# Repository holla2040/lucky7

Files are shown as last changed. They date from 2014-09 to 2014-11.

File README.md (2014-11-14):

Lucky7
======

7-Output Power Control Arduino Shield with sensor inputs and IR sensor<br><br>
Features<br>
1. 7 high-current (12A max) P-channel high-side MOSFETs with gate drivers. These switches have 30mOhm Rds when on. Each output has an LED indicator. 6 of the outputs are PWM controllable.<br>
2. The shield can operate up to 30VDC and supplies this voltage to the Arduino board.<br>
3. Two additional LEDs are connected to Arduino pin 8 and 13.<br>
4. 3 analog inputs: 2 for photocells, 1 for user button.<br>
5. 1 IR sensor input, such as TSOP38238.<br>
6. Input voltage sense to Arduino analog input A0.<br>
7. ATO fuse holder for wire protection in case of shorts to ground.<br>
8. Hardware design and firmware are released CC-BY-SA<br>
<br>
Fully populated and tested board is available for $20 + shipping.  Contact holla@montrosemakerspace.com for more information.
<br>
<br>
Only 10 available, order now!

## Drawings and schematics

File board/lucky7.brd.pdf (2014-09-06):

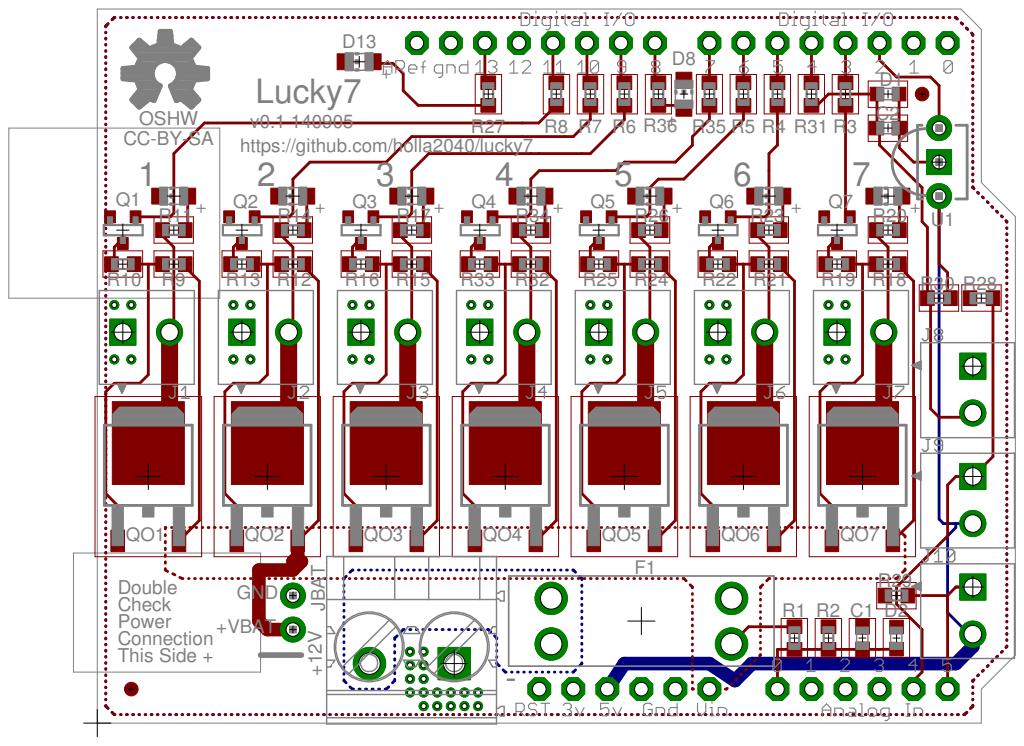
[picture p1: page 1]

- Double Check Power Connection This Side +

+VBAT

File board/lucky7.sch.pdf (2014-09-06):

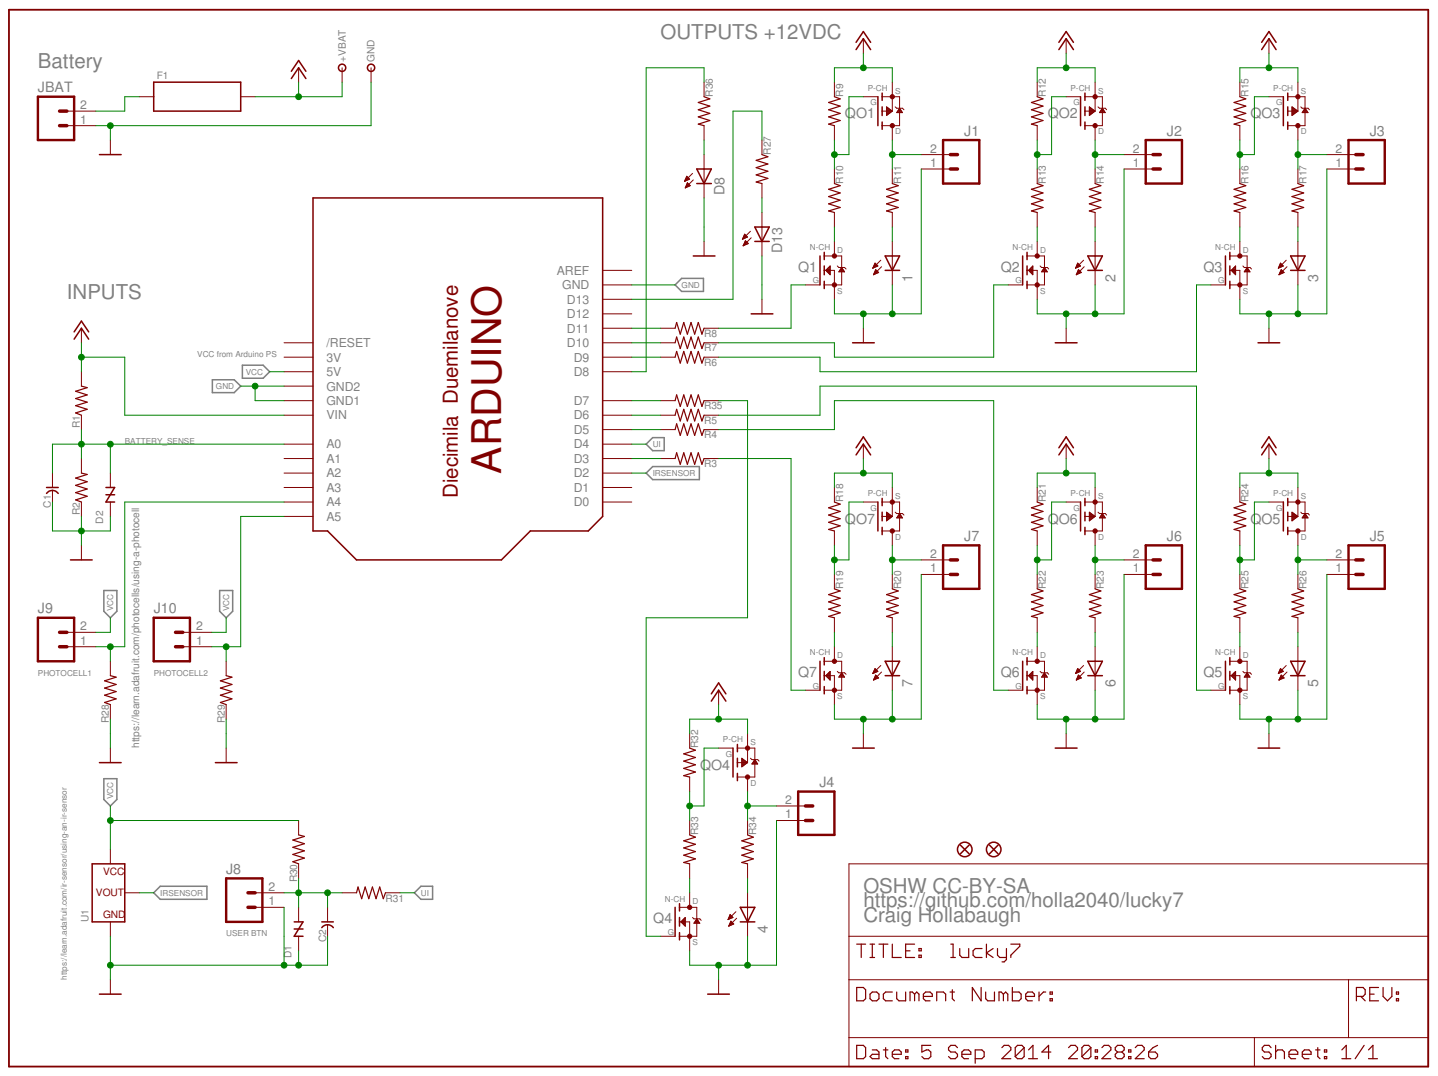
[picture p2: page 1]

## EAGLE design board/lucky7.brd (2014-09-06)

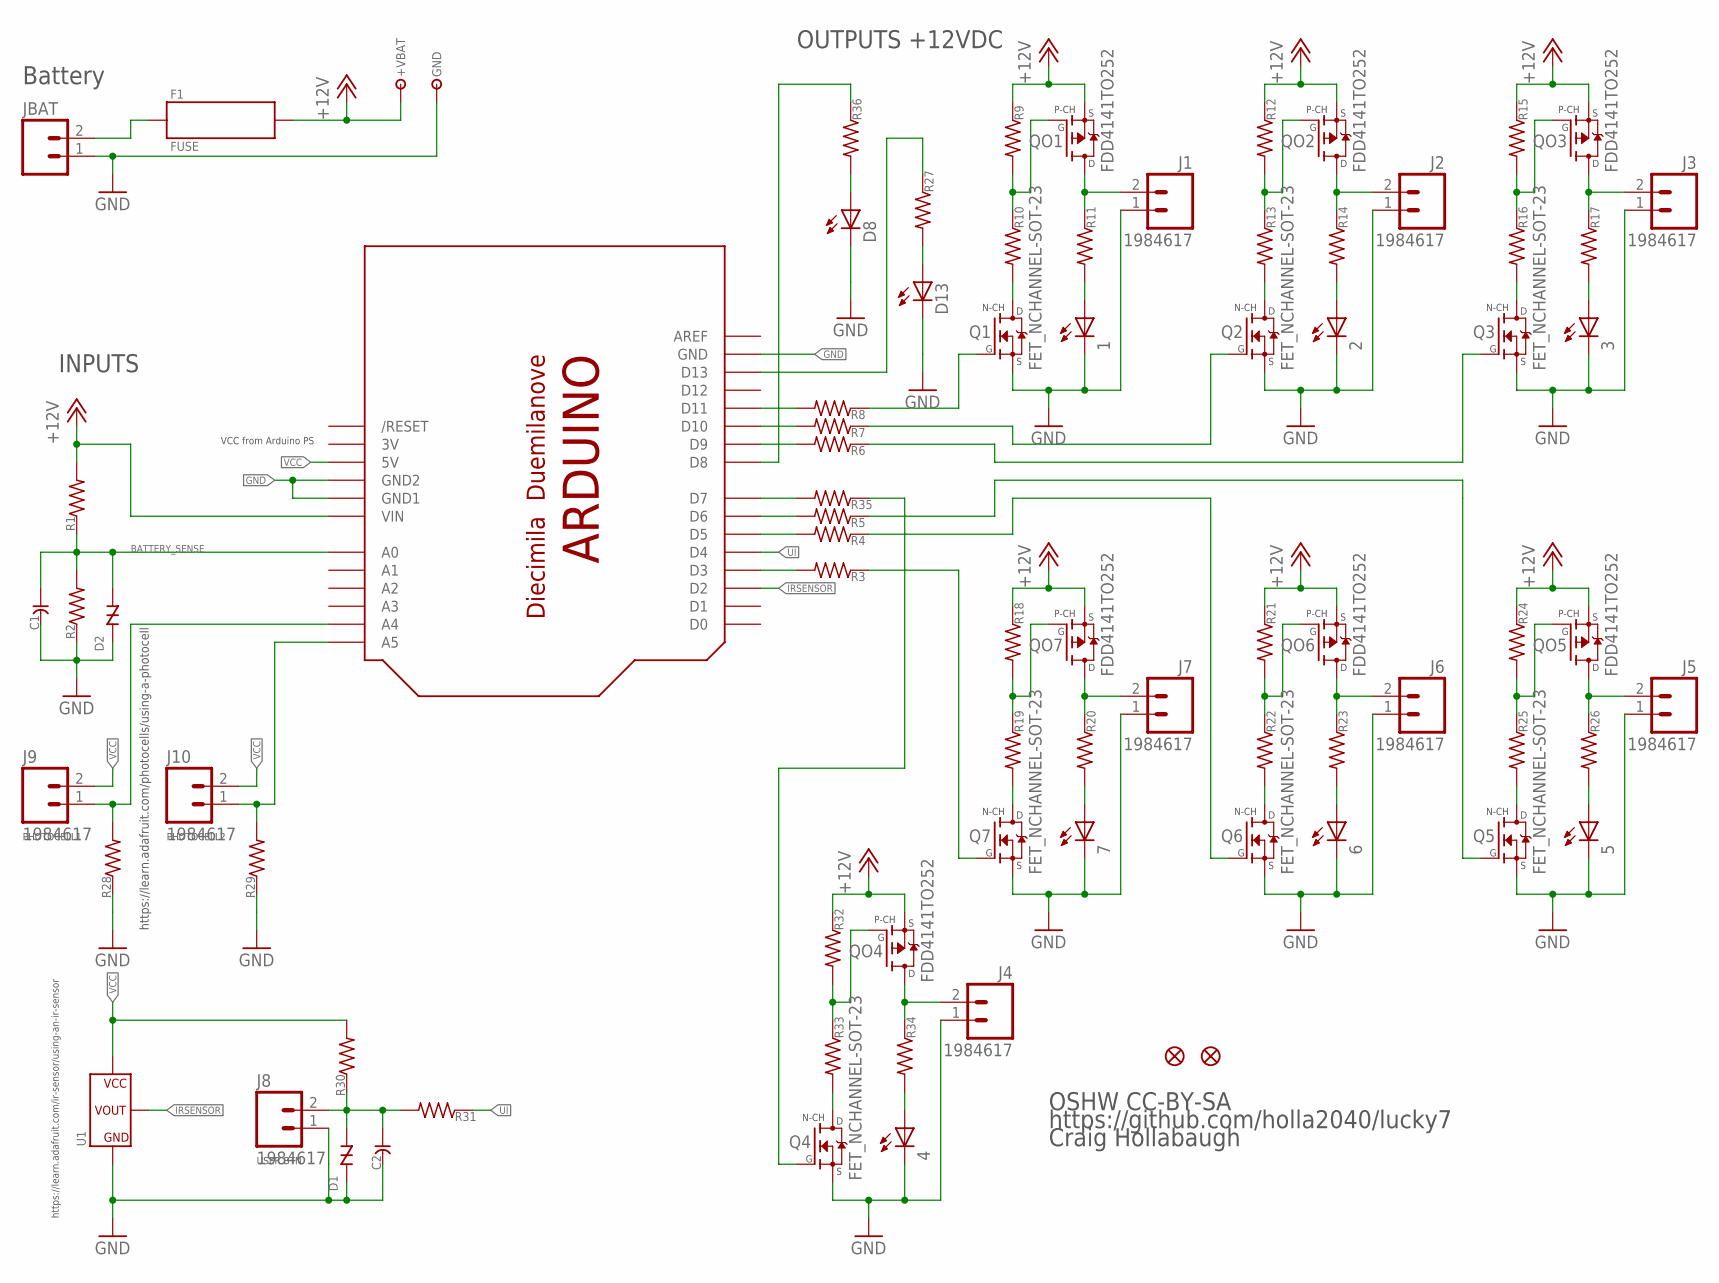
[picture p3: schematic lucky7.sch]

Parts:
1, 2, 3, 4, 5, 6, 7: LEDCHIP-LED0805; CHIP-LED0805
+VBAT: TESTPOINTTHRU; TPTHRU
C1, C2: C-USC0603; C0603
D1, D2: TVS0603; TVS-0603
D8, D13: LEDCHIP-LED0805; CHIP-LED0805
F1: FUSE; FUSE-3557-2
GND: TESTPOINTTHRU; TPTHRU
J1, J2, J3, J4, J5, J6, J7, J8, J9, J10: 1984617
JBAT: M02-6.35MM; OSTT702
JP1, JP2: FIDUCIAL1X2; FIDUCIAL-1X2
Q1, Q2, Q3, Q4, Q5, Q6, Q7: FET_NCHANNEL-SOT-23; SOT-23
QO1, QO2, QO3, QO4, QO5, QO6, QO7: FDD4141TO252; TO252
R1, R2, R3, R4, R5, R6, R7, R8, R9, R10, R11, R12, R13, R14, R15, R16, R17, R18, R19, R20, R21, R22, R23, R24, R25, R26, R27, R28, R29, R30, R31, R32, R33, R34, R35, R36: R-US_R0603; R0603
U1: IRDETECTOR-THRU
U100: ARDUINO-BPLACE

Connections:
3V: U100.3V
+12V: +VBAT.1, F1.2@1, F1.2@2, QO1.2 (S), QO2.2 (S), QO3.2 (S), QO4.2 (S), QO5.2 (S), QO6.2 (S), QO7.2 (S), R1.2, R9.1, R12.1, R15.1, R18.1, R21.1, R24.1, R32.1, U100.VIN
BATTERY_SENSE: C1.1, D2.1, R1.1, R2.2, U100.A0
GND: 1.C, 2.C, 3.C, 4.C, 5.C, 6.C, 7.C, C1.2, C2.2, D1.2, D2.2, D8.C, D13.C, GND.1, J1.1, J2.1, J3.1, J4.1, J5.1, J6.1, J7.1, J8.1, JBAT.1, Q1.3 (S), Q2.3 (S), Q3.3 (S), Q4.3 (S), Q5.3 (S), Q6.3 (S), Q7.3 (S), R2.1, R28.1, R29.1, U1.GND, U100.GND, U100.GND1, U100.GND2
IRSENSOR: U1.VOUT, U100.D2
unnamed: QO1.1 (G), R9.2, R10.1
unnamed: Q1.1 (D), R10.2
unnamed: R8.2, U100.D11
unnamed: J9.1, R28.2, U100.A4
unnamed: 1.A, R11.2
unnamed: R7.2, U100.D10
unnamed: R6.2, U100.D9
unnamed: R5.2, U100.D6
unnamed: R4.2, U100.D5
unnamed: R3.2, U100.D3
unnamed: QO2.1 (G), R12.2, R13.1
unnamed: Q2.1 (D), R13.2
unnamed: 2.A, R14.2
unnamed: QO3.1 (G), R15.2, R16.1
unnamed: Q3.1 (D), R16.2
unnamed: 3.A, R17.2
unnamed: QO7.1 (G), R18.2, R19.1
unnamed: Q7.1 (D), R19.2
unnamed: 7.A, R20.2
unnamed: QO6.1 (G), R21.2, R22.1
unnamed: Q6.1 (D), R22.2
unnamed: 6.A, R23.2
unnamed: QO5.1 (G), R24.2, R25.1
unnamed: Q5.1 (D), R25.2
unnamed: 5.A, R26.2
unnamed: Q1.2 (G), R8.1
unnamed: Q2.2 (G), R7.1
unnamed: Q3.2 (G), R6.1
unnamed: Q5.2 (G), R5.1
unnamed: Q6.2 (G), R4.1
unnamed: Q7.2 (G), R3.1
unnamed: J10.1, R29.2, U100.A5
unnamed: C2.1, D1.1, J8.2, R30.1, R31.2
unnamed: D13.A, R27.2
unnamed: R27.1, U100.D13
unnamed: QO4.1 (G), R32.2, R33.1
unnamed: Q4.1 (D), R33.2
unnamed: D8.A, R36.2
unnamed: R36.1, U100.D8
unnamed: 4.A, R34.2
unnamed: Q4.2 (G), R35.1
unnamed: R35.2, U100.D7
O1: J1.2, QO1.3 (D), R11.1
O2: J2.2, QO2.3 (D), R14.1
O3: J3.2, QO3.3 (D), R17.1
O4: J4.2, QO4.3 (D), R34.1
O5: J5.2, QO5.3 (D), R26.1
O6: J6.2, QO6.3 (D), R23.1
O7: J7.2, QO7.3 (D), R20.1
UI: R31.1, U100.D4
VBAT: F1.1@1, F1.1@2, JBAT.2
VCC: J9.2, J10.2, R30.2, U1.VCC, U100.5V

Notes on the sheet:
PHOTOCELL1
PHOTOCELL2
https://learn.adafruit.com/photocells/using-a-photocell
USER BTN
VCC from Arduino PS
https://learn.adafruit.com/ir-sensor/using-an-ir-sensor
INPUTS
OUTPUTS +12VDC
Battery
https://github.com/holla2040/lucky7
OSHW CC-BY-SA
Craig Hollabaugh

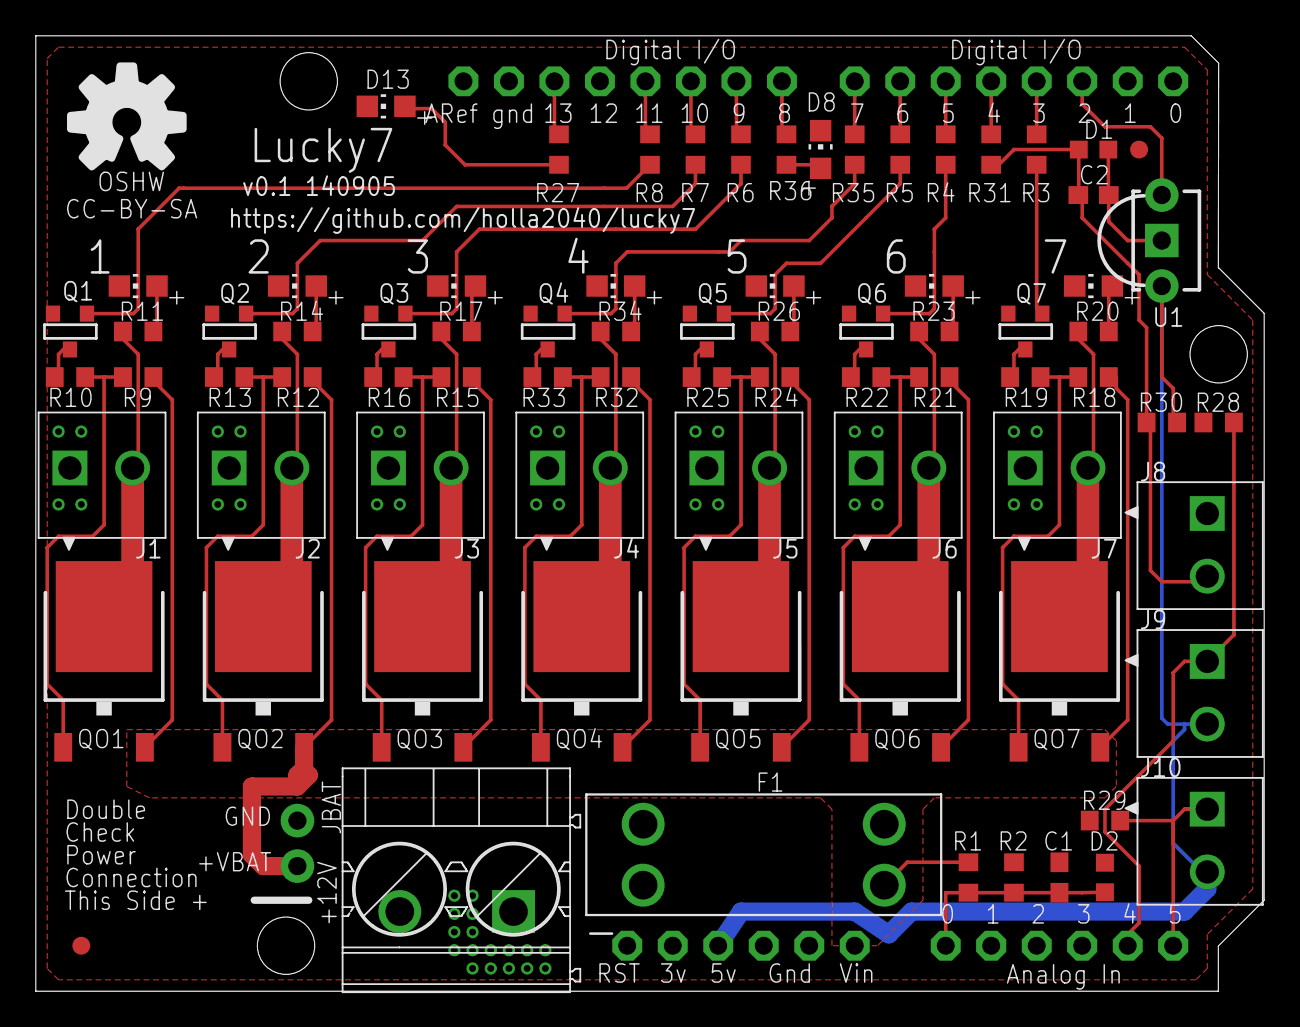
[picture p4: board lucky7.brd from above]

Board: 2 copper layers, 68.6 x 53.3 mm, 81 parts (0 on the bottom side), 56 nets.

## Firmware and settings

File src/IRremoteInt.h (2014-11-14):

/*
 * IRremote
 * Version 0.1 July, 2009
 * Copyright 2009 Ken Shirriff
 * For details, see http://arcfn.com/2009/08/multi-protocol-infrared-remote-library.html
 *
 * Modified by Paul Stoffregen <paul@pjrc.com> to support other boards and timers
 *
 * Interrupt code based on NECIRrcv by Joe Knapp
 * http://www.arduino.cc/cgi-bin/yabb2/YaBB.pl?num=1210243556
 * Also influenced by http://zovirl.com/2008/11/12/building-a-universal-remote-with-an-arduino/
 *
 * JVC and Panasonic protocol added by Kristian Lauszus (Thanks to zenwheel and other people at the original blog post)
 */

#ifndef IRremoteint_h
#define IRremoteint_h

#if defined(ARDUINO) && ARDUINO >= 100
#include <Arduino.h>
#else
#include <WProgram.h>
#endif

// define which timer to use
//
// Uncomment the timer you wish to use on your board.  If you
// are using another library which uses timer2, you have options
// to switch IRremote to use a different timer.

// Arduino Mega
#if defined(__AVR_ATmega1280__) || defined(__AVR_ATmega2560__)
  //#define IR_USE_TIMER1   // tx = pin 11
  #define IR_USE_TIMER2     // tx = pin 9
  //#define IR_USE_TIMER3   // tx = pin 5
  //#define IR_USE_TIMER4   // tx = pin 6
  //#define IR_USE_TIMER5   // tx = pin 46

// Teensy 1.0
#elif defined(__AVR_AT90USB162__)
  #define IR_USE_TIMER1     // tx = pin 17

// Teensy 2.0
#elif defined(__AVR_ATmega32U4__)
  //#define IR_USE_TIMER1   // tx = pin 14
  //#define IR_USE_TIMER3   // tx = pin 9
  #define IR_USE_TIMER4_HS  // tx = pin 10

// Teensy++ 1.0 & 2.0
#elif defined(__AVR_AT90USB646__) || defined(__AVR_AT90USB1286__)
  //#define IR_USE_TIMER1   // tx = pin 25
  #define IR_USE_TIMER2     // tx = pin 1
  //#define IR_USE_TIMER3   // tx = pin 16

// Sanguino
#elif defined(__AVR_ATmega644P__) || defined(__AVR_ATmega644__)
  //#define IR_USE_TIMER1   // tx = pin 13
  #define IR_USE_TIMER2     // tx = pin 14

// Atmega8
#elif defined(__AVR_ATmega8P__) || defined(__AVR_ATmega8__)
  #define IR_USE_TIMER1   // tx = pin 9

// Arduino Duemilanove, Diecimila, LilyPad, Mini, Fio, etc
#else
  #define IR_USE_TIMER1   // tx = pin 9
  //#define IR_USE_TIMER2     // tx = pin 3
#endif



#ifdef F_CPU
#define SYSCLOCK F_CPU     // main Arduino clock
#else
#define SYSCLOCK 16000000  // main Arduino clock
#endif

#define ERR 0
#define DECODED 1


// defines for setting and clearing register bits
#ifndef cbi
#define cbi(sfr, bit) (_SFR_BYTE(sfr) &= ~_BV(bit))
#endif
#ifndef sbi
#define sbi(sfr, bit) (_SFR_BYTE(sfr) |= _BV(bit))
#endif

// Pulse parms are *50-100 for the Mark and *50+100 for the space
// First MARK is the one after the long gap
// pulse parameters in usec
#define NEC_HDR_MARK	9000
#define NEC_HDR_SPACE	4500
#define NEC_BIT_MARK	560
#define NEC_ONE_SPACE	1600
#define NEC_ZERO_SPACE	560
#define NEC_RPT_SPACE	2250

#define SONY_HDR_MARK	2400
#define SONY_HDR_SPACE	600
#define SONY_ONE_MARK	1200
#define SONY_ZERO_MARK	600
#define SONY_RPT_LENGTH 45000
#define SONY_DOUBLE_SPACE_USECS  500  // usually ssee 713 - not using ticks as get number wrapround

// SA 8650B
#define SANYO_HDR_MARK	3500  // seen range 3500
#define SANYO_HDR_SPACE	950 //  seen 950
#define SANYO_ONE_MARK	2400 // seen 2400  
#define SANYO_ZERO_MARK 700 //  seen 700
#define SANYO_DOUBLE_SPACE_USECS  800  // usually ssee 713 - not using ticks as get number wrapround
#define SANYO_RPT_LENGTH 45000

// Mitsubishi RM 75501
// 14200 7 41 7 42 7 42 7 17 7 17 7 18 7 41 7 18 7 17 7 17 7 18 7 41 8 17 7 17 7 18 7 17 7 

// #define MITSUBISHI_HDR_MARK	250  // seen range 3500
#define MITSUBISHI_HDR_SPACE	350 //  7*50+100
#define MITSUBISHI_ONE_MARK	1950 // 41*50-100
#define MITSUBISHI_ZERO_MARK  750 // 17*50-100
// #define MITSUBISHI_DOUBLE_SPACE_USECS  800  // usually ssee 713 - not using ticks as get number wrapround
// #define MITSUBISHI_RPT_LENGTH 45000


#define RC5_T1		889
#define RC5_RPT_LENGTH	46000

#define RC6_HDR_MARK	2666
#define RC6_HDR_SPACE	889
#define RC6_T1		444
#define RC6_RPT_LENGTH	46000

#define SHARP_BIT_MARK 245
#define SHARP_ONE_SPACE 1805
#define SHARP_ZERO_SPACE 795
#define SHARP_GAP 600000
#define SHARP_TOGGLE_MASK 0x3FF
#define SHARP_RPT_SPACE 3000

#define DISH_HDR_MARK 400
#define DISH_HDR_SPACE 6100
#define DISH_BIT_MARK 400
#define DISH_ONE_SPACE 1700
#define DISH_ZERO_SPACE 2800
#define DISH_RPT_SPACE 6200
#define DISH_TOP_BIT 0x8000

#define PANASONIC_HDR_MARK 3502
#define PANASONIC_HDR_SPACE 1750
#define PANASONIC_BIT_MARK 502
#define PANASONIC_ONE_SPACE 1244
#define PANASONIC_ZERO_SPACE 400

#define JVC_HDR_MARK 8000
#define JVC_HDR_SPACE 4000
#define JVC_BIT_MARK 600
#define JVC_ONE_SPACE 1600
#define JVC_ZERO_SPACE 550
#define JVC_RPT_LENGTH 60000

#define LG_HDR_MARK 8000
#define LG_HDR_SPACE 4000
#define LG_BIT_MARK 600
#define LG_ONE_SPACE 1600
#define LG_ZERO_SPACE 550
#define LG_RPT_LENGTH 60000

#define SAMSUNG_HDR_MARK  5000
#define SAMSUNG_HDR_SPACE 5000
#define SAMSUNG_BIT_MARK  560
#define SAMSUNG_ONE_SPACE 1600
#define SAMSUNG_ZERO_SPACE  560
#define SAMSUNG_RPT_SPACE 2250


#define SHARP_BITS 15
#define DISH_BITS 16

#define TOLERANCE 25  // percent tolerance in measurements
#define LTOL (1.0 - TOLERANCE/100.) 
#define UTOL (1.0 + TOLERANCE/100.) 

#define _GAP 5000 // Minimum map between transmissions
#define GAP_TICKS (_GAP/USECPERTICK)

#define TICKS_LOW(us) (int) (((us)*LTOL/USECPERTICK))
#define TICKS_HIGH(us) (int) (((us)*UTOL/USECPERTICK + 1))

// receiver states
#define STATE_IDLE     2
#define STATE_MARK     3
#define STATE_SPACE    4
#define STATE_STOP     5

// information for the interrupt handler
typedef struct {
  uint8_t recvpin;           // pin for IR data from detector
  uint8_t rcvstate;          // state machine
  uint8_t blinkflag;         // TRUE to enable blinking of pin 13 on IR processing
  unsigned int timer;     // state timer, counts 50uS ticks.
  unsigned int rawbuf[RAWBUF]; // raw data
  uint8_t rawlen;         // counter of entries in rawbuf
} 
irparams_t;

// Defined in IRremote.cpp
extern volatile irparams_t irparams;

// IR detector output is active low
#define MARK  0
#define SPACE 1

#define TOPBIT 0x80000000

#define NEC_BITS 32
#define SONY_BITS 12
#define SANYO_BITS 12
#define MITSUBISHI_BITS 16
#define MIN_RC5_SAMPLES 11
#define MIN_RC6_SAMPLES 1
#define PANASONIC_BITS 48
#define JVC_BITS 16
#define LG_BITS 28
#define SAMSUNG_BITS 32
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

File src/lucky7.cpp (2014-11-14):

#include "lucky7.h"
#include "IRremote.h"

IRrecv irrecv(IR);
decode_results results;

void Lucky7::setup() {
  o1 = 0;
  o2 = 0;
  o3 = 0;
  o4 = 0;
  o5 = 0;
  o6 = 0;
  o7 = 0;
  o8 = 0;
  o13 = 0;
  pinMode(O1,OUTPUT);
  pinMode(O2,OUTPUT);
  pinMode(O3,OUTPUT);
  pinMode(O4,OUTPUT);
  pinMode(O5,OUTPUT);
  pinMode(O6,OUTPUT);
  pinMode(O7,OUTPUT);
  pinMode(O8,OUTPUT);
  pinMode(O13,OUTPUT);
  timeout = 0;

  pinMode(A4,INPUT);
  pinMode(A5,INPUT);
  aveptr = 0;

  irrecv.enableIRIn(); // Start the receiver
}


uint32_t Lucky7::loop() {
  uint8_t i = (aveptr++) % AVECNT;
  uint32_t rv = 0;
  analogWrite(O1,o1);
  analogWrite(O2,o2);
  analogWrite(O3,o3);
  digitalWrite(O4,o4);
  analogWrite(O5,o5);
  analogWrite(O6,o6);
  analogWrite(O7,o7);
  digitalWrite(O8,o8);
  digitalWrite(O13,o13);

  pc1[i] = analogRead(A4);
  pc2[i] = analogRead(A5);
  bc[i]  = analogRead(A0);

  if (millis() > timeout) {
      if (irrecv.decode(&results)) {
        rv = results.value;
        timeout = millis() + 500;
      }
    } else {
      irrecv.resume(); // Receive the next value
    }
  return rv;
}

uint16_t Lucky7::photocell1() {
    uint16_t sum = 0;
    uint8_t i;
    for (i = 0; i < AVECNT; i++) {
        sum += pc1[i];
    }
    return (uint16_t)(sum/AVECNT);
}

uint16_t Lucky7::photocell2() {
    uint32_t sum = 0;
    uint8_t i;
    for (i = 0; i < AVECNT; i++) {
        sum += pc2[i];
    }
    return (uint16_t)(sum/AVECNT);
}

float Lucky7::batteryVoltage() {
    uint32_t sum = 0;
    uint8_t i;
    for (i = 0; i < AVECNT; i++) {
        sum += bc[i];
    }
    return (float)(sum/AVECNT)*BVSCALE;
}


// this could be done more efficiently
void Lucky7::o1MoveTo(uint8_t v, uint16_t stepdelay) {
    int16_t i;
    if (v == o1) {
        return;
    } 
    if (v > o1) {
        for (i = o1; i < v; i++) {
            //Serial.println(i);
            analogWrite(O1,i);
            delayMicroseconds(stepdelay);
        }
    } else {
        for (i = o1; i >= v; i--) {
            //Serial.println(i);
            analogWrite(O1,i);
            delayMicroseconds(stepdelay);
        }
    }
    o1 = v;
}

// this could be done more efficiently
void Lucky7::o2MoveTo(uint8_t v, uint16_t stepdelay) {
    int16_t i;
    if (v == o2) {
        return;
    } 
    if (v > o2) {
        for (i = o2; i < v; i++) {
            //Serial.println(i);
            analogWrite(O2,i);
            delayMicroseconds(stepdelay);
        }
    } else {
        for (i = o2; i >= v; i--) {
            //Serial.println(i);
            analogWrite(O2,i);
            delayMicroseconds(stepdelay);
        }
    }
    o2 = v;
}

// this could be done more efficiently
void Lucky7::o3MoveTo(uint8_t v, uint16_t stepdelay) {
    int16_t i;
    if (v == o3) {
        return;
    } 
    if (v > o3) {
        for (i = o3; i < v; i++) {
            //Serial.println(i);
            analogWrite(O3,i);
            delayMicroseconds(stepdelay);
        }
    } else {
        for (i = o3; i >= v; i--) {
            //Serial.println(i);
            analogWrite(O3,i);
            delayMicroseconds(stepdelay);
        }
    }
    o3 = v;
}

// this could be done more efficiently
void Lucky7::o5MoveTo(uint8_t v, uint16_t stepdelay) {
    int16_t i;
    if (v == o5) {
        return;
    } 
    if (v > o5) {
        for (i = o5; i < v; i++) {
            //Serial.println(i);
            analogWrite(O5,i);
            delayMicroseconds(stepdelay);
        }
    } else {
        for (i = o5; i >= v; i--) {
            //Serial.println(i);
            analogWrite(O5,i);
            delayMicroseconds(stepdelay);
        }
    }
    o5 = v;
}

// this could be done more efficiently
void Lucky7::o6MoveTo(uint8_t v, uint16_t stepdelay) {
    int16_t i;
    if (v == o6) {
        return;
    } 
    if (v > o6) {
        for (i = o6; i < v; i++) {
            //Serial.println(i);
            analogWrite(O6,i);
            delayMicroseconds(stepdelay);
        }
    } else {
        for (i = o6; i >= v; i--) {
            //Serial.println(i);
            analogWrite(O6,i);
            delayMicroseconds(stepdelay);
        }
    }
    o6 = v;
}

// this could be done more efficiently
void Lucky7::o7MoveTo(uint8_t v, uint16_t stepdelay) {
    int16_t i;
    if (v == o7) {
        return;
    } 
    if (v > o7) {
        for (i = o7; i < v; i++) {
            //Serial.println(i);
            analogWrite(O7,i);
            delayMicroseconds(stepdelay);
        }
    } else {
        for (i = o7; i >= v; i--) {
            //Serial.println(i);
            analogWrite(O7,i);
            delayMicroseconds(stepdelay);
        }
    }
    o7 = v;
}

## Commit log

2014-09-06 initial add
    [lucky7.brd, lucky7.sch]
2014-09-13 initial add for NMNSH variant
    [NMNSH F-16 Lighting Controller.brd, NMNSH F-16 Lighting Controller.sch]
2014-09-13 moving these to new repo
    [NMNSH F-16 Lighting Controller.brd, NMNSH F-16 Lighting Controller.sch]
